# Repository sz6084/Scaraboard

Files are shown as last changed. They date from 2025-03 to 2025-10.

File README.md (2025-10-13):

# Scaraboard
A keyboard with some Scaramouche art on it!

hackboard-case

### Inspiration

I wanted to create a keyboard to replace my old keyboard that I spilled a smoothie over, a (surprisingly decent and fully-sized) membrane keyboard. Scaraboard has 88 switches, 1 rpi pico, and no LEDs (I don't want the hassle and my current keyboard doesn't have it anyways, though RGB in a future one would be cool). Also Genshin Impact.

### Challenge

I had only just designed my macropad, and now i had to scale it up. I followed an online guide and consulted my trusty friend who had more experience than I did. I also asked questions in the Hack Club Slack.

### Specifications

## Bill of Material
| Part | Qty | Price | Link |
| --- | --- | --- | --- |
| PCB | 5 | $21.50 | https://cart.jlcpcb.com/quote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 |
| MX Switches | 88 | $17.60 | https://mechanicalkeyboards.com/products/gateron-ks-3-milky-yellow-pro-50g-linear-pcb-mount |
| Keycaps | 88 | $13.99 | https://www.amazon.com/Doubleshot-Mechanical-Keyboard-Compatiability-Keyboads/dp/B0F7H32LKC |
| Stabilizers | 1 | $10.00 | https://cannonkeys.com/products/cherry-stabilizers?variant=32257338998895 |
| 1N4148 Diode | 88 | $8.80 | https://www.digikey.com/en/products/detail/onsemi/1N4148/458603 |
| Orpheus Pi Pico | 2 | --- | https://orpheuspico.hackclub.com |
| Subtotal | --- | $77.89 | --- |
| Approx. Total Price (with shipping) | --- | $106.33 | --- |

Others:
 - Case is 3d printed in PLA
 - 4x M3x12 screw
 - 4x M3x4 heat set inserts
 - KMK firmware

Schematic            |  PCB         |   Case
:-------------------------:|:-------------------------:|:-------------------------:|
|  |  PCB |  hackboard-case |

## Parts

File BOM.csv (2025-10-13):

Part | Qty | Price | Link
PCB | 5 | 21.50 | https://cart.jlcpcb.com/quote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
MX Switches | 88 | $17.60 | https://mechanicalkeyboards.com/products/gateron-ks-3-milky-yellow-pro-50g-linear-pcb-mount
Keycaps | 88 | $19.90 | https://www.amazon.com/Pwnage-Full-PBT-Keycap-Set/dp/B09WJNRLNC
Stabilizers | 1 | $10.00 | https://cannonkeys.com/products/cherry-stabilizers?variant=32257338998895
1N4148 Diode | 88 | $8.80 | https://www.digikey.com/en/products/detail/onsemi/1N4148/458603
Orpheus Pi Pico | 2 | --- | https://orpheuspico.hackclub.com
Subtotal | --- | $83.89 | ---
Approx. Total Price (w/ shipping) | --- | $106.33 | ---

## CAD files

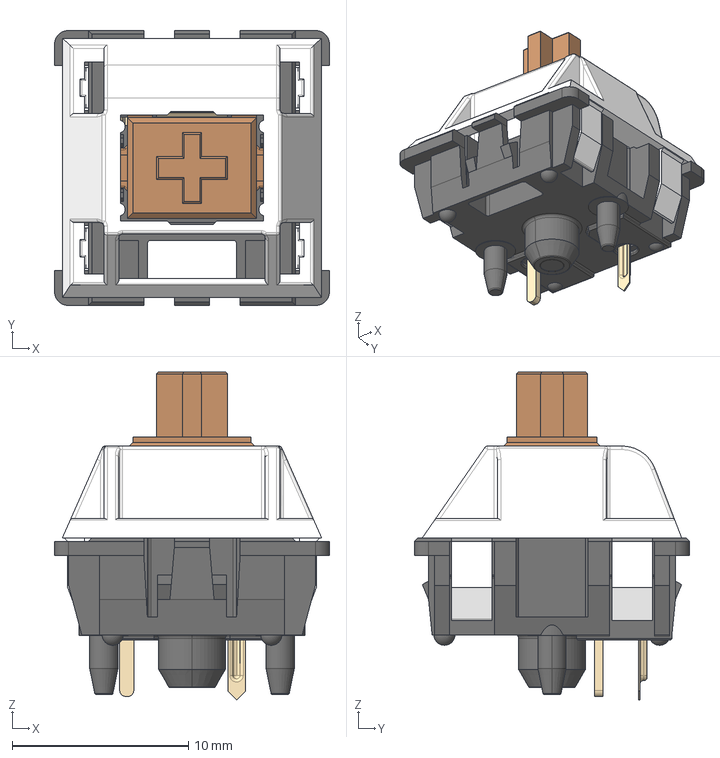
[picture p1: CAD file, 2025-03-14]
PCB/3dmodels/MX_PCB.step
15.6 x 15.6 x 18.6 mm

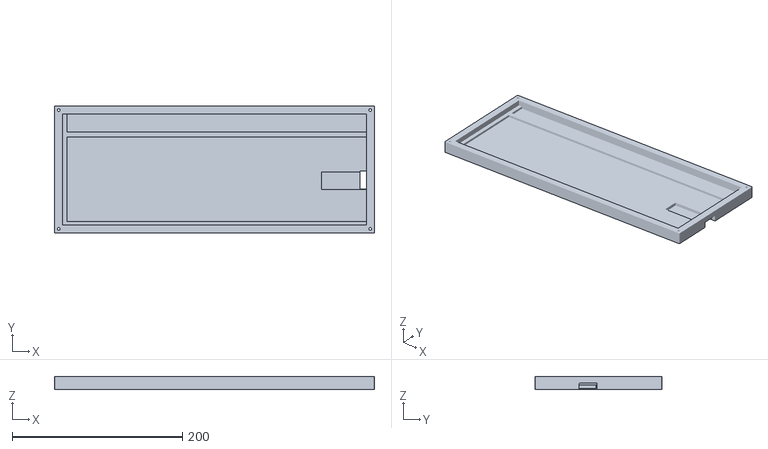
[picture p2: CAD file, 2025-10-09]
production/hackboard-bottom-case v23.stl
375.7 x 149.3 x 15.0

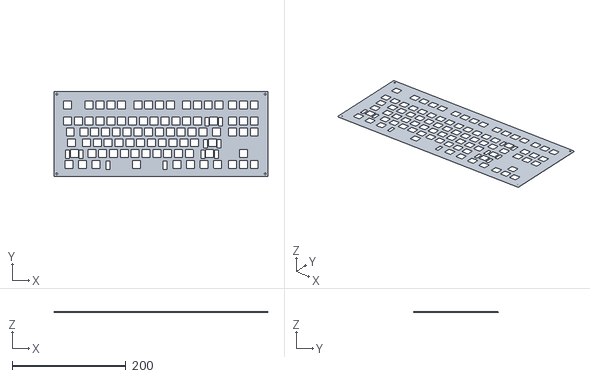
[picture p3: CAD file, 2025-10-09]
production/hackboard-top-plate v7.stl
376.7 x 150.3 x 1.50

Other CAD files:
CAD/hackboard-case v3.f3z

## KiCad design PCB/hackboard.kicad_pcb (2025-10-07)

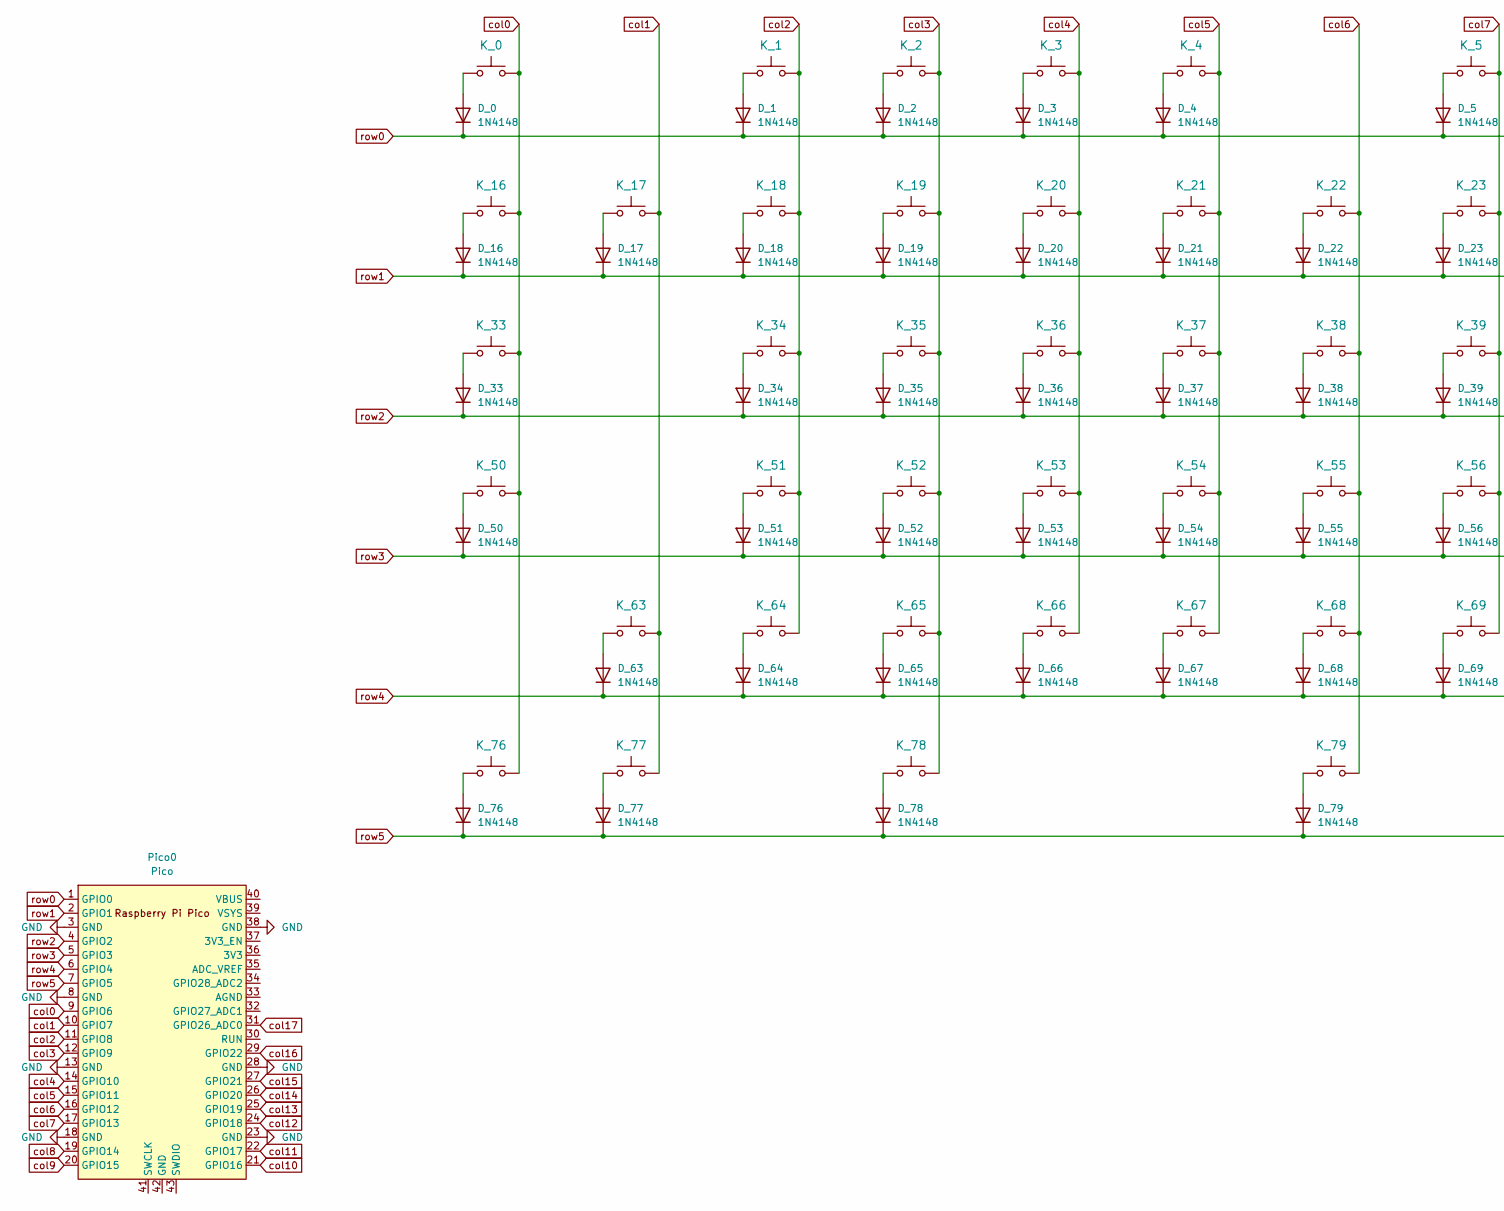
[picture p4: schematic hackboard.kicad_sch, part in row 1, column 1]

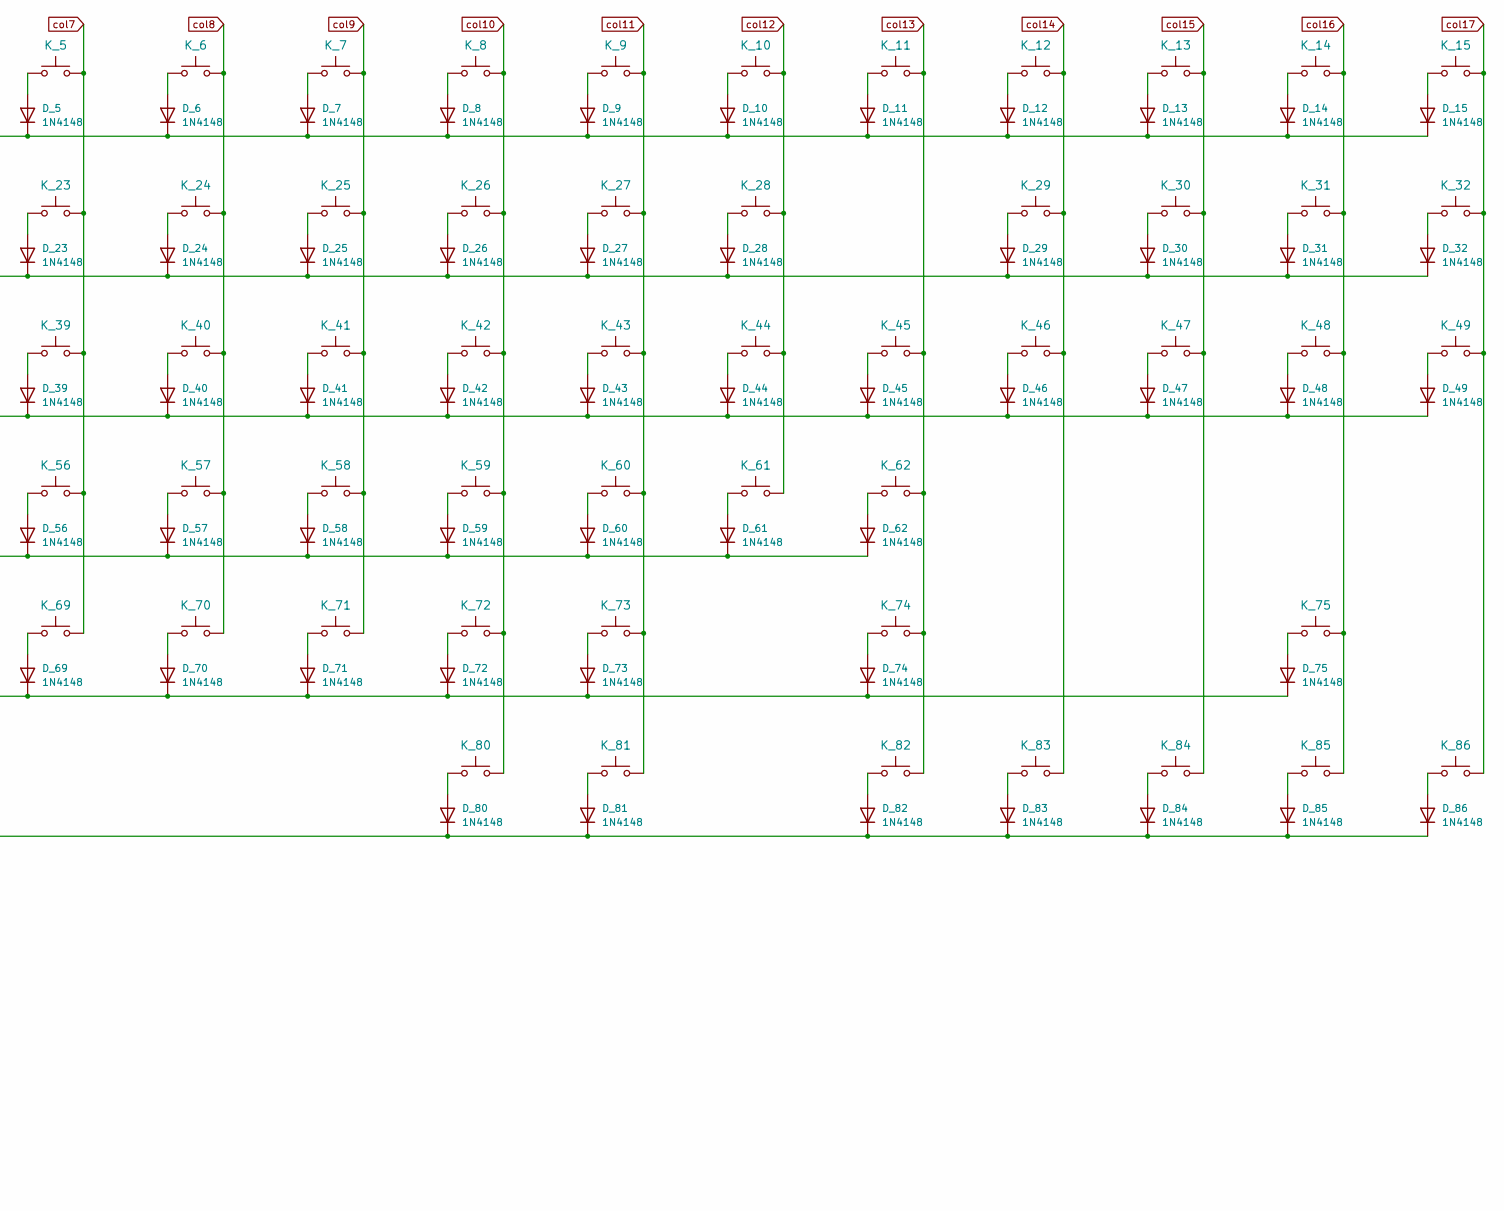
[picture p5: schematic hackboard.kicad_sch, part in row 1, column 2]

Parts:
D_0, D_1, D_2, D_3, D_4, D_5, D_6, D_7, D_8, D_9, D_10, D_11, D_12, D_13, D_14, D_15, D_16, D_17, D_18, D_19, D_20, D_21, D_22, D_23, D_24, D_25, D_26, D_27, D_28, D_29, D_30, D_31, D_32, D_33, D_34, D_35, D_36, D_37, D_38, D_39, D_40, D_41, D_42, D_43, D_44, D_45, D_46, D_47, D_48, D_49, D_50, D_51, D_52, D_53, D_54, D_55, D_56, D_57, D_58, D_59, D_60, D_61, D_62, D_63, D_64, D_65, D_66, D_67, D_68, D_69, D_70, D_71, D_72, D_73, D_74, D_75, D_76, D_77, D_78, D_79, D_80, D_81, D_82, D_83, D_84, D_85, D_86: 1N4148; D_DO-35_SOD27_P7.62mm_Horizontal
K_0, K_1, K_2, K_3, K_4, K_5, K_6, K_7, K_8, K_9, K_10, K_11, K_12, K_13, K_14, K_15, K_16, K_17, K_18, K_19, K_20, K_21, K_22, K_23, K_24, K_25, K_26, K_27, K_28, K_30, K_31, K_32, K_34, K_35, K_36, K_37, K_38, K_39, K_40, K_41, K_42, K_43, K_44, K_45, K_47, K_48, K_49, K_51, K_52, K_53, K_54, K_55, K_56, K_57, K_58, K_59, K_60, K_61, K_64, K_65, K_66, K_67, K_68, K_69, K_70, K_71, K_72, K_73, K_75, K_84, K_85, K_86: KEYSW; SW_Cherry_MX_1.00u_PCB
K_29: KEYSW; SW_Cherry_MX_2.00u_PCB
K_33, K_46: KEYSW; SW_Cherry_MX_1.50u_PCB
K_50: KEYSW; SW_Cherry_MX_1.75u_PCB
K_62, K_63: KEYSW; SW_Cherry_MX_2.25u_PCB
K_74: KEYSW; SW_Cherry_MX_2.75u_PCB
K_76, K_77, K_78, K_80, K_81, K_82, K_83: KEYSW; SW_Cherry_MX_1.25u_PCB
K_79: KEYSW; SW_Cherry_MX_6.25u_PCB
Pico0: Pico; RPi_Pico_SMD_TH

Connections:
GND: Pico0.3 (GND), Pico0.8 (GND), Pico0.13 (GND), Pico0.18 (GND), Pico0.23 (GND), Pico0.28 (GND), Pico0.38 (GND)
unnamed: D_0.2 (A), K_0.1
unnamed: D_1.2 (A), K_1.1
unnamed: D_2.2 (A), K_2.1
unnamed: D_3.2 (A), K_3.1
unnamed: D_4.2 (A), K_4.1
unnamed: D_5.2 (A), K_5.1
unnamed: D_6.2 (A), K_6.1
unnamed: D_7.2 (A), K_7.1
unnamed: D_8.2 (A), K_8.1
unnamed: D_9.2 (A), K_9.1
unnamed: D_10.2 (A), K_10.1
unnamed: D_11.2 (A), K_11.1
unnamed: D_12.2 (A), K_12.1
unnamed: D_13.2 (A), K_13.1
unnamed: D_14.2 (A), K_14.1
unnamed: D_15.2 (A), K_15.1
unnamed: D_16.2 (A), K_16.1
unnamed: D_17.2 (A), K_17.1
unnamed: D_18.2 (A), K_18.1
unnamed: D_19.2 (A), K_19.1
unnamed: D_20.2 (A), K_20.1
unnamed: D_21.2 (A), K_21.1
unnamed: D_22.2 (A), K_22.1
unnamed: D_23.2 (A), K_23.1
unnamed: D_24.2 (A), K_24.1
unnamed: D_25.2 (A), K_25.1
unnamed: D_26.2 (A), K_26.1
unnamed: D_27.2 (A), K_27.1
unnamed: D_28.2 (A), K_28.1
unnamed: D_29.2 (A), K_29.1
unnamed: D_30.2 (A), K_30.1
unnamed: D_31.2 (A), K_31.1
unnamed: D_32.2 (A), K_32.1
unnamed: D_33.2 (A), K_33.1
unnamed: D_34.2 (A), K_34.1
unnamed: D_35.2 (A), K_35.1
unnamed: D_36.2 (A), K_36.1
unnamed: D_37.2 (A), K_37.1
unnamed: D_38.2 (A), K_38.1
unnamed: D_39.2 (A), K_39.1
unnamed: D_40.2 (A), K_40.1
unnamed: D_41.2 (A), K_41.1
unnamed: D_42.2 (A), K_42.1
unnamed: D_43.2 (A), K_43.1
unnamed: D_44.2 (A), K_44.1
unnamed: D_45.2 (A), K_45.1
unnamed: D_46.2 (A), K_46.1
unnamed: D_47.2 (A), K_47.1
unnamed: D_48.2 (A), K_48.1
unnamed: D_49.2 (A), K_49.1
unnamed: D_50.2 (A), K_50.1
unnamed: D_51.2 (A), K_51.1
unnamed: D_52.2 (A), K_52.1
unnamed: D_53.2 (A), K_53.1
unnamed: D_54.2 (A), K_54.1
unnamed: D_55.2 (A), K_55.1
unnamed: D_56.2 (A), K_56.1
unnamed: D_57.2 (A), K_57.1
unnamed: D_58.2 (A), K_58.1
unnamed: D_59.2 (A), K_59.1
unnamed: D_60.2 (A), K_60.1
unnamed: D_61.2 (A), K_61.1
unnamed: D_62.2 (A), K_62.1
unnamed: D_63.2 (A), K_63.1
unnamed: D_64.2 (A), K_64.1
unnamed: D_65.2 (A), K_65.1
unnamed: D_66.2 (A), K_66.1
unnamed: D_67.2 (A), K_67.1
unnamed: D_68.2 (A), K_68.1
unnamed: D_69.2 (A), K_69.1
unnamed: D_70.2 (A), K_70.1
unnamed: D_71.2 (A), K_71.1
unnamed: D_72.2 (A), K_72.1
unnamed: D_73.2 (A), K_73.1
unnamed: D_74.2 (A), K_74.1
unnamed: D_75.2 (A), K_75.1
unnamed: D_76.2 (A), K_76.1
unnamed: D_77.2 (A), K_77.1
unnamed: D_78.2 (A), K_78.1
unnamed: D_79.2 (A), K_79.1
unnamed: D_80.2 (A), K_80.1
unnamed: D_81.2 (A), K_81.1
unnamed: D_82.2 (A), K_82.1
unnamed: D_83.2 (A), K_83.1
unnamed: D_84.2 (A), K_84.1
unnamed: D_85.2 (A), K_85.1
unnamed: D_86.2 (A), K_86.1
col0: K_0.2, K_16.2, K_33.2, K_50.2, K_76.2, Pico0.9 (GPIO6)
col1: K_17.2, K_63.2, K_77.2, Pico0.10 (GPIO7)
col2: K_1.2, K_18.2, K_34.2, K_51.2, K_64.2, Pico0.11 (GPIO8)
col3: K_2.2, K_19.2, K_35.2, K_52.2, K_65.2, K_78.2, Pico0.12 (GPIO9)
col4: K_3.2, K_20.2, K_36.2, K_53.2, K_66.2, Pico0.14 (GPIO10)
col5: K_4.2, K_21.2, K_37.2, K_54.2, K_67.2, Pico0.15 (GPIO11)
col6: K_22.2, K_38.2, K_55.2, K_68.2, K_79.2, Pico0.16 (GPIO12)
col7: K_5.2, K_23.2, K_39.2, K_56.2, K_69.2, Pico0.17 (GPIO13)
col8: K_6.2, K_24.2, K_40.2, K_57.2, K_70.2, Pico0.19 (GPIO14)
col9: K_7.2, K_25.2, K_41.2, K_58.2, K_71.2, Pico0.20 (GPIO15)
col10: K_8.2, K_26.2, K_42.2, K_59.2, K_72.2, K_80.2, Pico0.21 (GPIO16)
col11: K_9.2, K_27.2, K_43.2, K_60.2, K_73.2, K_81.2, Pico0.22 (GPIO17)
col12: K_10.2, K_28.2, K_44.2, K_61.2, Pico0.24 (GPIO18)
col13: K_11.2, K_45.2, K_62.2, K_74.2, K_82.2, Pico0.25 (GPIO19)
col14: K_12.2, K_29.2, K_46.2, K_83.2, Pico0.26 (GPIO20)
col15: K_13.2, K_30.2, K_47.2, K_84.2, Pico0.27 (GPIO21)
col16: K_14.2, K_31.2, K_48.2, K_75.2, K_85.2, Pico0.29 (GPIO22)
col17: K_15.2, K_32.2, K_49.2, K_86.2, Pico0.31 (GPIO26_ADC0)
row0: D_0.1 (K), D_1.1 (K), D_2.1 (K), D_3.1 (K), D_4.1 (K), D_5.1 (K), D_6.1 (K), D_7.1 (K), D_8.1 (K), D_9.1 (K), D_10.1 (K), D_11.1 (K), D_12.1 (K), D_13.1 (K), D_14.1 (K), D_15.1 (K), Pico0.1 (GPIO0)
row1: D_16.1 (K), D_17.1 (K), D_18.1 (K), D_19.1 (K), D_20.1 (K), D_21.1 (K), D_22.1 (K), D_23.1 (K), D_24.1 (K), D_25.1 (K), D_26.1 (K), D_27.1 (K), D_28.1 (K), D_29.1 (K), D_30.1 (K), D_31.1 (K), D_32.1 (K), Pico0.2 (GPIO1)
row2: D_33.1 (K), D_34.1 (K), D_35.1 (K), D_36.1 (K), D_37.1 (K), D_38.1 (K), D_39.1 (K), D_40.1 (K), D_41.1 (K), D_42.1 (K), D_43.1 (K), D_44.1 (K), D_45.1 (K), D_46.1 (K), D_47.1 (K), D_48.1 (K), D_49.1 (K), Pico0.4 (GPIO2)
row3: D_50.1 (K), D_51.1 (K), D_52.1 (K), D_53.1 (K), D_54.1 (K), D_55.1 (K), D_56.1 (K), D_57.1 (K), D_58.1 (K), D_59.1 (K), D_60.1 (K), D_61.1 (K), D_62.1 (K), Pico0.5 (GPIO3)
row4: D_63.1 (K), D_64.1 (K), D_65.1 (K), D_66.1 (K), D_67.1 (K), D_68.1 (K), D_69.1 (K), D_70.1 (K), D_71.1 (K), D_72.1 (K), D_73.1 (K), D_74.1 (K), D_75.1 (K), Pico0.6 (GPIO4)
row5: D_76.1 (K), D_77.1 (K), D_78.1 (K), D_79.1 (K), D_80.1 (K), D_81.1 (K), D_82.1 (K), D_83.1 (K), D_84.1 (K), D_85.1 (K), D_86.1 (K), Pico0.7 (GPIO5)

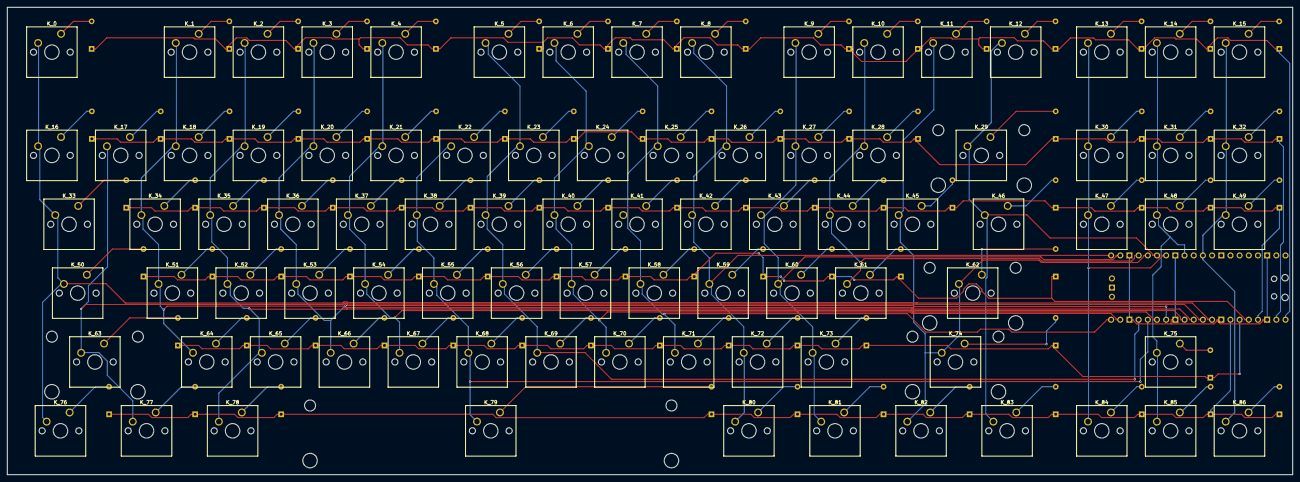
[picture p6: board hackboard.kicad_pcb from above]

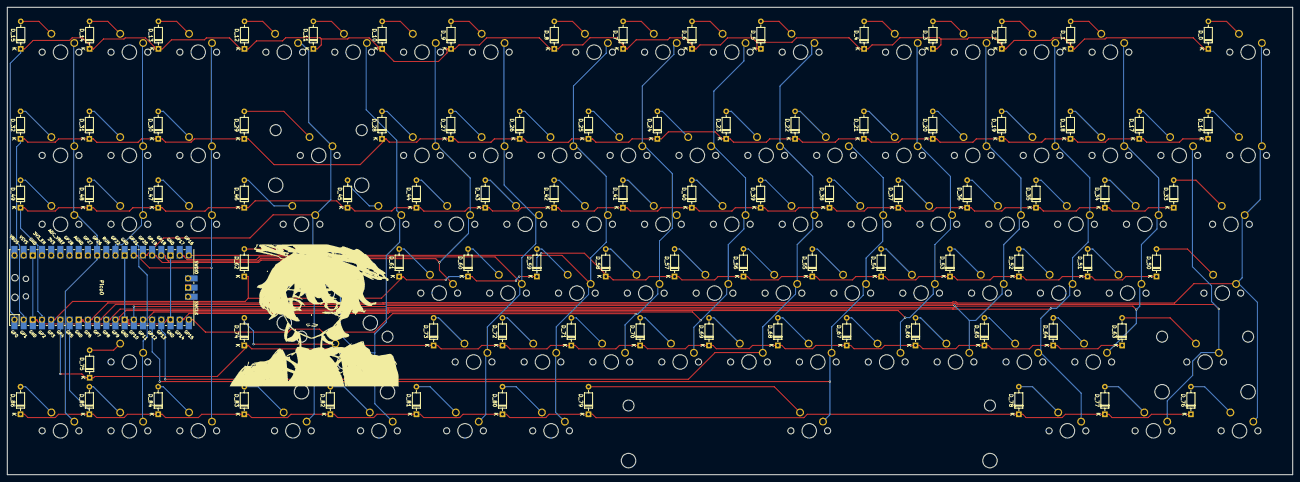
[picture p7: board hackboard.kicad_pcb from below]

Board: 2 copper layers, 355.7 x 129.3 mm, 175 parts (88 on the bottom side), 112 nets.

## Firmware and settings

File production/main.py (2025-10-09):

### KMK FILE - FIRMWARE ###
# You import all the IOs of your board
import board

# These are imports from the kmk library
from kmk.kmk_keyboard import KMKKeyboard
from kmk.scanners.keypad import KeysScanner
from kmk.keys import KC
from kmk.modules.macros import Press, Release, Tap, Macros

# This is the main instance of your keyboard
keyboard = KMKKeyboard()

# Add the macro extension
macros = Macros()
keyboard.modules.append(macros)

# Define your pins here!
# PINS = [board.D3, board.D4, board.D2, board.D1]
keyboard.row_pins = (board.GP0, board.GP1, board.GP2, board.GP3, board.GP4, board.GP5)
keyboard.col_pins = (board.GP6, board.GP7, board.GP8, board.GP9, board.GP10, board.GP11, board.GP12, board.GP13, board.GP14, board.GP15, board.GP16, board.GP17, board.GP18, board.GP19, board.GP20, board.GP21, board.GP22, board.GP26)

# Tell kmk we are not using a key matrix
# keyboard.matrix = KeysScanner(
#     pins=PINS,
#     value_when_pressed=False,
# )

# Here you define the buttons corresponding to the pins
# Look here for keycodes: https://github.com/KMKfw/kmk_firmware/blob/main/docs/en/keycodes.md
# And here for macros: https://github.com/KMKfw/kmk_firmware/blob/main/docs/en/macros.md
keyboard.keymap = [
    [  # Base layer
        KC.ESC,  KC.N1,   KC.N2,   KC.N3,   KC.N4,   KC.N5,   KC.N6,   KC.N7,   KC.N8,   KC.N9,   KC.N0,   KC.MINS,  KC.EQL,   KC.BSPC,  KC.INS,   KC.HOME,  KC.PGUP,
        KC.TAB,  KC.Q,    KC.W,    KC.E,    KC.R,    KC.T,    KC.Y,    KC.U,    KC.I,    KC.O,    KC.P,    KC.LBRC,  KC.RBRC,  KC.BSLS,  KC.DEL,   KC.END,   KC.PGDN,
        KC.CAPS, KC.A,    KC.S,    KC.D,    KC.F,    KC.G,    KC.H,    KC.J,    KC.K,    KC.L,    KC.SCLN,  KC.QUOT,  KC.ENT,
        KC.LSFT, KC.Z,    KC.X,    KC.C,    KC.V,    KC.B,    KC.N,    KC.M,    KC.COMM,  KC.DOT,   KC.SLSH,  KC.RSFT,  KC.UP,
        KC.LCTL, KC.LGUI, KC.LALT, KC.SPC,  KC.RALT, KC.RGUI, KC.MENU, KC.RCTL,  KC.LEFT,  KC.DOWN,  KC.RGHT
    ],
    [  # Layer 1 (Function layer)
        KC.GRV,  KC.F1,   KC.F2,   KC.F3,   KC.F4,   KC.F5,   KC.F6,   KC.F7,   KC.F8,   KC.F9,   KC.F10,  KC.F11,  KC.F12,   KC.DEL,   KC.PSCR,  KC.SLCK,  KC.PAUS,
        KC.TRNS, KC.TRNS, KC.TRNS, KC.TRNS, KC.TRNS, KC.TRNS, KC.TRNS, KC.TRNS, KC.TRNS, KC.TRNS, KC.TRNS, KC.TRNS, KC.TRNS, KC.TRNS,  KC.TRNS, KC.TRNS, KC.TRNS,
        KC.TRNS, KC.TRNS, KC.TRNS, KC.TRNS, KC.TRNS, KC.TRNS, KC.TRNS, KC.TRNS, KC.TRNS, KC.TRNS, KC.TRNS, KC.TRNS, KC.TRNS,
        KC.TRNS, KC.TRNS, KC.TRNS, KC.TRNS, KC.TRNS, KC.TRNS, KC.TRNS, KC.TRNS, KC.TRNS, KC.TRNS, KC.TRNS, KC.TRNS, KC.TRNS,
        KC.TRNS, KC.TRNS, KC.TRNS, KC.TRNS, KC.TRNS, KC.TRNS, KC.TRNS, KC.TRNS, KC.TRNS, KC.TRNS, KC.TRNS
    ]
]

# Start kmk!
if __name__ == '__main__':
    keyboard.go()

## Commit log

2025-03-10 Initialized KiCAD project
    [hackboard.kicad_pcb, hackboard.kicad_sch]
2025-03-14 Added KiCad-RP-PICO submodule to the project.
2025-03-14 Initialized keyboard using auto-generated layout tool and added a 3D Model
    [MX_PCB.step, hackboard.kicad_pcb, hackboard.kicad_sch]
2025-03-15 Moved MCB
    [hackboard.kicad_pcb]
2025-03-15 Finished Routing
    [hackboard.kicad_pcb]
2025-03-15 Moved diodes
    [hackboard.kicad_pcb]
2025-03-16 Updated symbols and routing
    [hackboard.kicad_pcb, hackboard.kicad_sch]
2025-03-17 Removed unused row
    [hackboard.kicad_pcb, hackboard.kicad_sch]
2025-03-23 Changed silkscreen art
    [hackboard.kicad_pcb]
2025-03-31 Added missing key in keymap
    [main.py]
2025-10-07 Add BOM.csv
2025-10-07 Uploaded CAD file
    [hackboard-case v3.f3z, hackboard.kicad_pcb]
2025-10-07 Update README.md
    Added PCB to BOM
2025-10-07 Added BOM.csv as an exception to .gitignore
    [BOM.csv]
2025-10-08 Update README.md
    Added Keycaps and Stabilizers to BOM as well as a Subtotal Row. Updated Total Price
2025-10-08 Update BOM.csv
    Updated to align with the BOM in the README.MD
    [BOM.csv]
2025-10-09 Moved production folder and added STLs and copy of firmware to it
    [hackboard-bottom-case v23.stl, hackboard-top-plate v7.stl]
2025-10-13 Update README.md
    Changed MCU from Raspberry to Orpheus
2025-10-13 Update BOM.csv
    Changed MCU from Raspberry Pi Pico to Orpheus
    [BOM.csv]
